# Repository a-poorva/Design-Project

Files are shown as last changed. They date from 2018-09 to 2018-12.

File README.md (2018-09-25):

# Design-Project

Design Skills Project (Variable Light Intensity)

Functional Specifications

1. LED light that is button-activated to switch between the following operating modes:
a. Off
b. Brightest
c. Intermediate Brightness
d. Least Bright
e. Flashing @ 2 Hz
2. Self-contained device with LED and button exposed.

Extra credit possibilities:
1. Battery life indicator
2. Waterproof enclosure
3. You tell us!

Constraints
1. Run on single battery up to 9 V
2. Electronics connected to a single PCB (can be single- or double-sided)
3. Cannot weight more than 1 lb
4. Cannot have a single dimension > 6 in
5. Cannot cost more than $50 to duplicate unit
6. Battery must be easily replaceable

Evaluation
1. Minimize weight
2. Minimize size
3. Maximize Brightest mode
4. Minimize power draw / maximize battery life
5. Survive 3 foot drop with battery installed

Create-and-maintain a GitHub project repository to maintain version history of:
1. Mechanical CAD (PDFs + more)
2. Electronic CAD (PDFs + more)
3. Software
4. Testing data
5. Design history / notes
6. Specification sheets
7. Usage notes (README.md)
8. Kanban board / Issues / Milestones

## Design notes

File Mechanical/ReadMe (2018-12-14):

Mechanical Design

There are two designs, one being the elliptical cylinder design with magnets and the other being the black box for the Arduino Uno.

The cylinder has:
--> USB port
--> holes for LED/switch
--> Magnets

The box has 
--> holes for LED/Switch
--> Grooves on the lid
--> threaded holes for adding screws

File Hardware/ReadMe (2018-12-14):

Components used include:

1. Arduino Uno --> The PCB here is not routed as I used a protoboard. I have laid out the components as it might look on the shield.
2. Pushbutton - Adafruit
3. Resistors - R1, R2 -0402-01/16W-1%, SparkFun (100k)
4. Battery - G1, AB9V
5. LED - LED2, 5MM, Adafruit
6. Arduino Nano --> The PCB here is routed as I etched this board.

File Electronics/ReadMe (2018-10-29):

Electrical Schematics should allow for 

1. Variable intensity of light
2. On/Off 
3. Blinking at 2Hz

Components used: Arduino (nano?), LED, bypass capacitor, switch, voltage regulator

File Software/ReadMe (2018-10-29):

Making use of Arduino (nano?)

Things to focus on:
1. Interrupts
2. Switching between cases and making sure that the interrupt functions for each case

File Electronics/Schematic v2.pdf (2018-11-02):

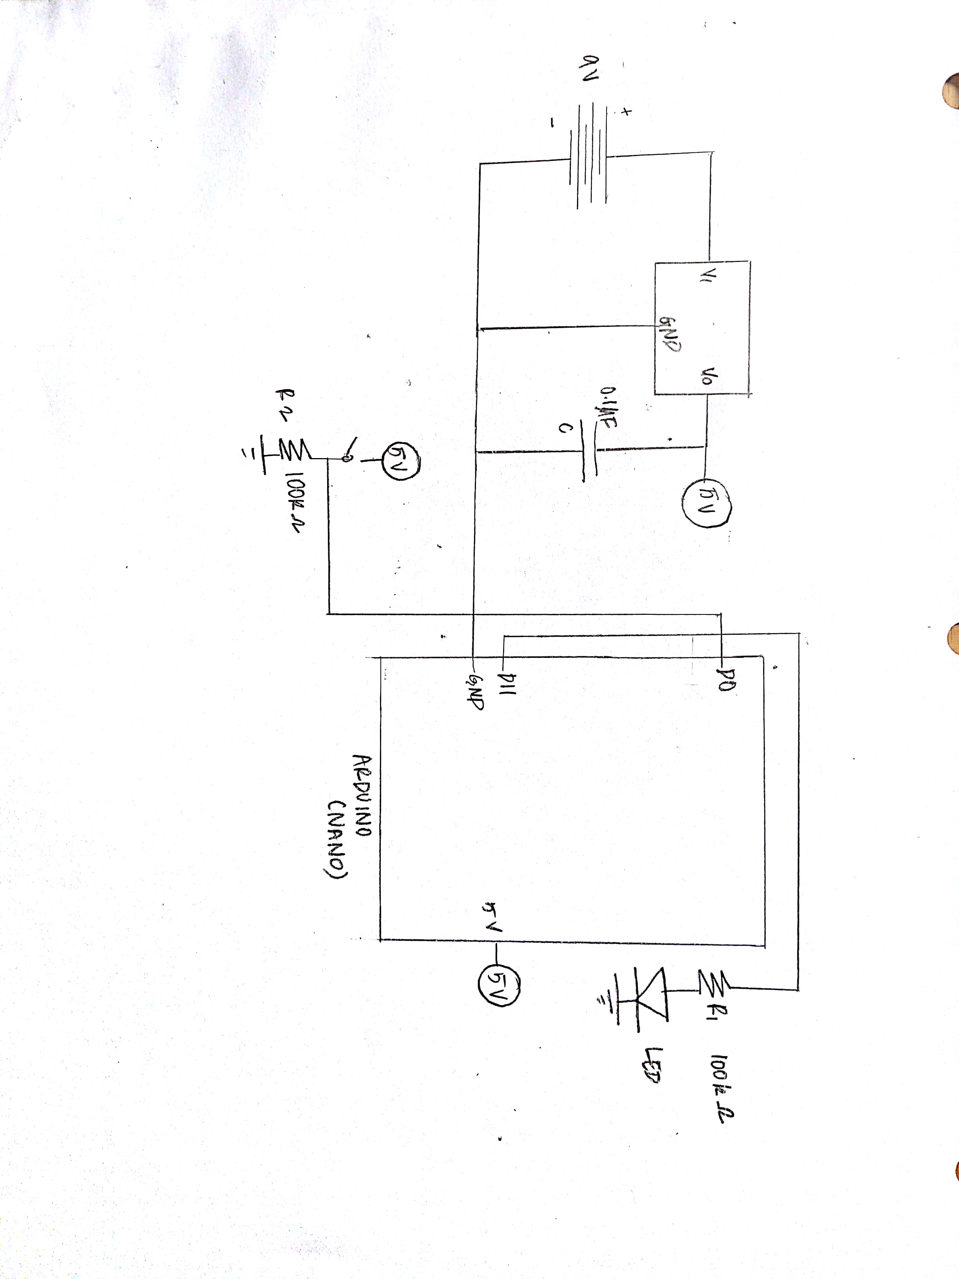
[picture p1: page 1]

Scanned by CamScanner

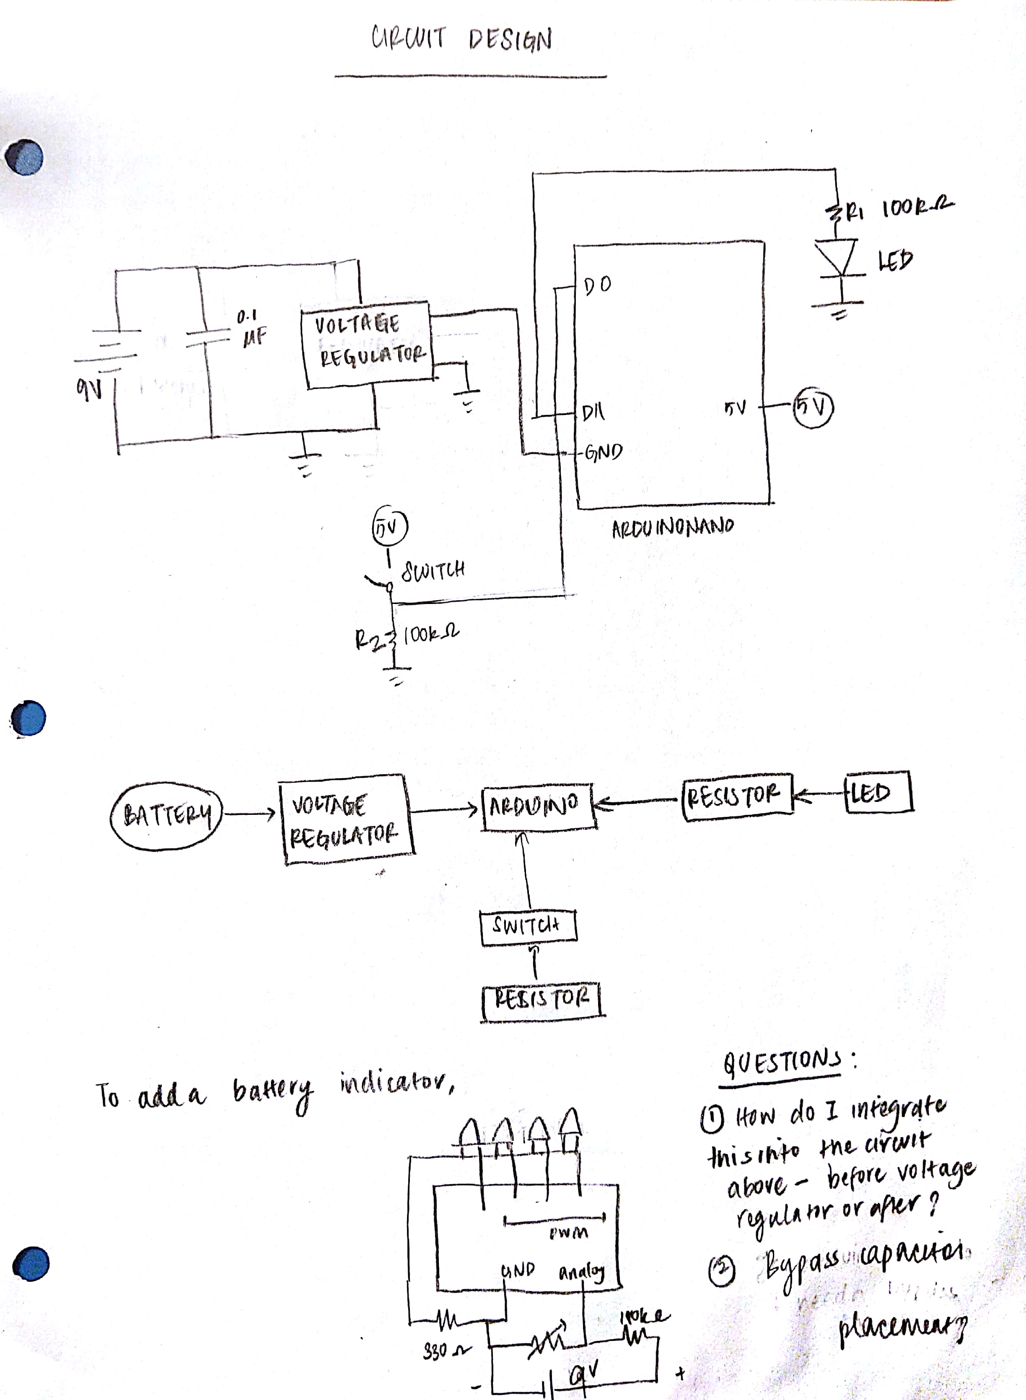
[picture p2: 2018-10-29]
Electronics/Electrical Schematic.jpg

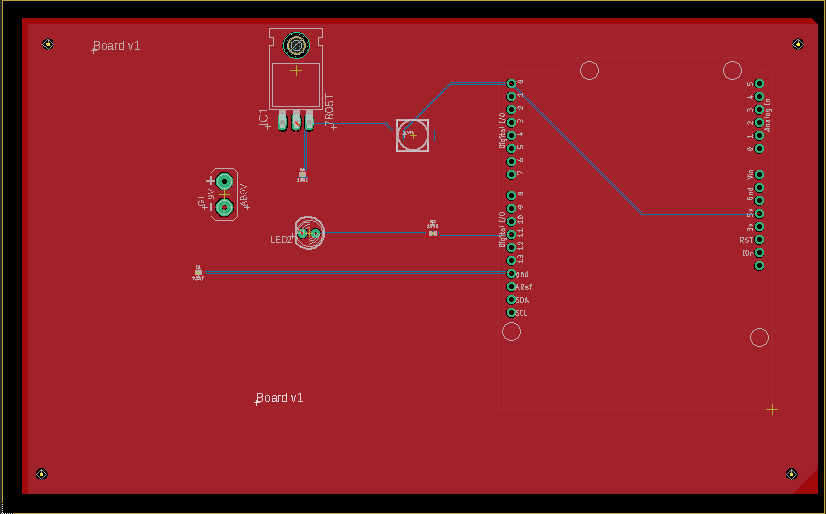
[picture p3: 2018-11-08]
Hardware/PCB in progress.png

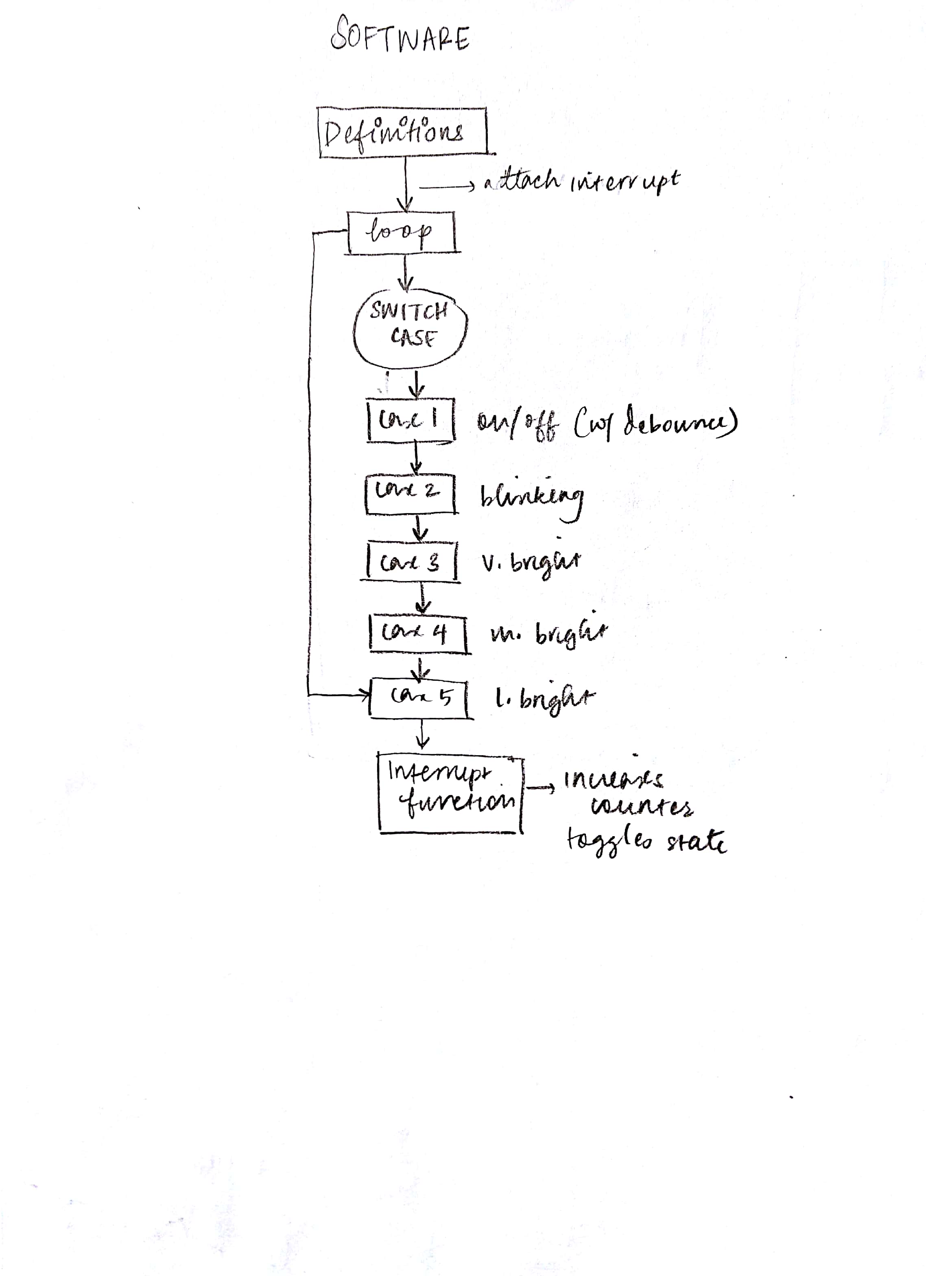
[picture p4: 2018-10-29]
Software/Flowchart.jpg

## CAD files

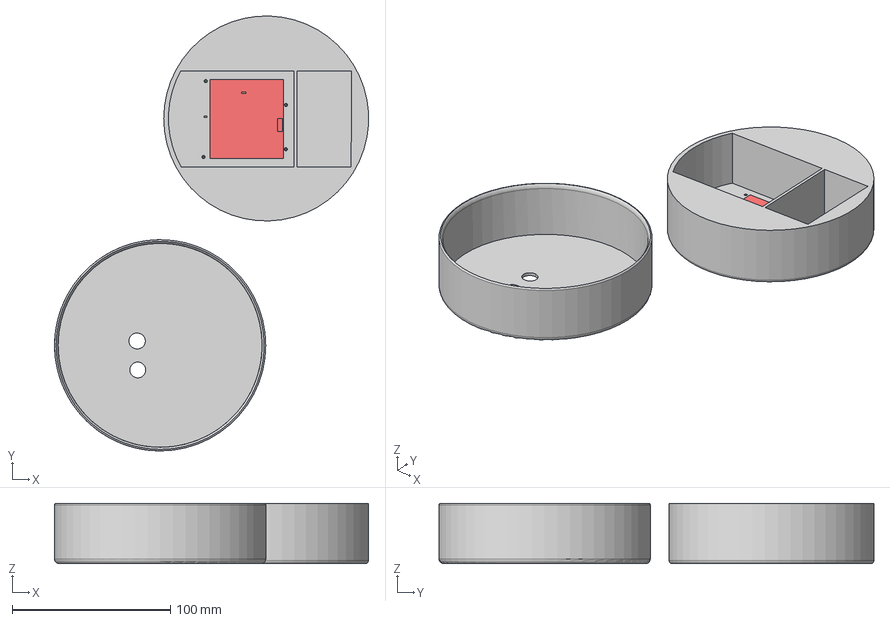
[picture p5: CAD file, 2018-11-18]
Mechanical/Cylinder3D v1.step
198.4 x 274.9 x 38.1 mm
Board
AB9V
LED5MM
100K
PUSHBUTTON_SMD_SJ
ARDUINOR3-BPLACE

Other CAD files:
Mechanical/Cylinder3D v1.f3d
Mechanical/Magnets_Design v1.f3d
Mechanical/Magnets_lid.f3d
Mechanical/arduino_body v1.f3d
Mechanical/arduino_lid v1.f3d
Mechanical/magnetidea v1.f3d
Mechanical/slidingdoor v1.f3d

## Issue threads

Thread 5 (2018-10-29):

Integration of Battery Indicator and placement of Bypass Capacitor

a-poorva, 2018-10-29:
- Not entirely sure how to integrate the battery indicator - while I have a rough circuit for it (the different LED's shown indicate different battery ranges), would I add this before the voltage regulator and bypass capacitor, or..?
- LIttle confused about the placement of the bypass capacitor, and if one is required after the voltage regulator as well since I plan on using an Arduino Nano.

a-poorva, 2018-11-04:
After a little research, I added a bypass capacitor to my circuit (check out Schematic v2). Would

Closed 2018-11-09.

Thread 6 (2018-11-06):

Software Review

a-poorva, 2018-11-06:
I'm having some problems with

1. Bouncing
I'm not sure what my program isn't accounting for.

2. Brightness changes
The LED isn't really getting any brighter, or less? Not sure what to change in my program. Should I just assign specific values for each level of brightness and remove the if statement?

mlp6, 2018-11-06:
It looks like you are using `digitalRead()` instead of `analogWrite()` for the PWM output in some of your case statements; am I misreading that?

W/r to the bouncing, what happens if you modulate the debounce delay?

mlp6, 2018-11-24:
I am not sure I totally follow how your debouncing logic should be working, but one thing I would be careful with with this line:
https://github.com/a-poorva/Design-Project/blob/8bf33d13c4cfb9eff1144b0b43db92085eee905f/Software/LEDv3.ino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

`ledState` is declared as an `int`; you are using it in that line more like a `bool`; can you declare it as a `bool` instead so that you can just toggle the state?  Also, I'm not a huge fan of assigning the value by flipping logical state; it would be easier to follow if you explicitly set and tested "on" and "off" states for the button.

a-poorva, 2018-12-02:
Hi Dr. Palmeri,

So I fixed my code a little, and while it changes states smoothly, the whole thing just runs on a loop continuously, not sure why. Would you mind taking a look at my code?

mlp6, 2018-12-03:
Your `loop()` function doesn't seem to ever call `button_press()`.

Closed 2018-12-05.

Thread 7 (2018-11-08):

PCB design

a-poorva, 2018-11-08:
1. I still have to assign this to Matt Brown, Dr. Richardson and Brinnae, since I sent them collaborator requests only last night/this morning. I'll add them later.
2. I started on my PCB design by adding polygon pores and then routing, but some of my connections seemed to disappear when I did that. Brinnae suggested routing and then adding polygon pores, and ripping up the ground connections? I'm a little confused about that, as well as to how to proceed beyond that (in terms of adding holes, vias, etc.)
3. Can I cut out all that extra space when I create my polygons?

a-poorva, 2018-11-09:
When I showed my design to Matt Brown today, he mentioned that part of the reason why my battery is just sort of floating around is because I didn't connect the Vcc in my schematic, though I labelled it?? Besides drawing connections between them, is there a more elegant way of approaching this problem?

a-poorva, 2018-11-09:
So I tried adding the source with the net tool, and I tried to reroute it but I noticed a problem(?) I saw last time as well:

1. My switch only has one connection?
2. The positive terminal of my battery doesn't seem to be connected to anything, but both connections seem to arise from the ground terminal.

Not sure what the issue is.

mlp6, 2018-11-09:
Will take a look in the morning.

a-poorva, 2018-11-09:
Uploaded a new version! Does this look a little better?

sphaerobolus, 2018-11-12:
Rather than creating new files for each version, take advantage of the version control system: Just upload the new version. The old version is still available as an old version of the same file.

Bypass capacitor C1 would be better between the regulator output and ground. It's not doing much good as used here, and might be doing harm.

Change the 100k current limiting resistor to a real value.

If you're doing this as a shield, do you even need the regulator? You could use Arduino's the on-board regulator. You pass through the Arduino's regulator if you use Vin stead of 5V as your supply.

a-poorva, 2018-11-13:
Thanks for your help, Matt! I've uploaded a new one (I have been uploading all my files so far, using the 'Upload files' button! Is that not the right way to do this?). Hope this one is better.

sphaerobolus, 2018-11-14:
I didn't use the right terminology when I suggested not creating new files. if you're using the desktop git client, the things you want to be doing are "commit" to save a new version of an existing file and "push" to put the file on the github server. If you're using the web client, I'm not sure what the best process is. You could edit the file, then paste in the new version and save it. You definitely don't want a bunch of files named "abcdv1.brd" and "abcdv2.brd". The git ecosystem takes care of the versions, you just commit new versions of existing files.

The board is looking good! Now I think all you need is to increase the width of traces. You can probably get away with 20mil, so go for that.

a-poorva, 2018-11-16:
Right. I'll be sure to look up how exactly to do that.

Thanks for your help!

Closed 2018-11-16.

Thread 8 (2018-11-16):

Header pins

a-poorva, 2018-11-16:
I just realised that I used the arduino board in my PCB instead of header pins. Is this the right way to do this? I'm not sure I understand the difference here.

sphaerobolus, 2018-11-17:
If you want this to be a shield for your Uno, you need to line up your connections to the Uno. To do this, you placed the Uno board as a component. If I understand you correctly, you might just be confused over semantics. Are you placing the Uno on your board? Or your board on the Uno? Doesn't matter, the holes still line up.

After fabricating the board, you'll put header pins in all those holes around the perimeter, then plug your board into the Uno.

Did I answer the right question?

a-poorva, 2018-11-17:
Right, so it doesn't matter, essentially, whether you use header pins or the actual board in your design, as long as the pins line up?

mlp6, 2018-11-17:
Yep!

Closed 2018-11-17.

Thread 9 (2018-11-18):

Cylinder Idea

a-poorva, 2018-11-18:
Please see the uploaded designs for reference.

I'm having a few problems with the following:

1. The arduino seems to be underneath the whole cylinder? I'm not sure why that's happening, or if I"m misinterpreting the design.
2. I wanted to have the lid of the cylinder screw on. I'm not sure if I've done the threading correctly.
3. The holes I've made in the lid seem to vanish whenever I try to dimension them - is this because I've made them incorrectly, or is there some other reason?
4. I'm a little uncertain about the dimensions of the holes I've made. Is there a stanard size we're supposed to use?

Any other feedback would be great!

ps178, 2018-11-19:
Could you upload the .f3d version of your CAD design.
You also need to upload the 2D rendering of your design. You can find this under MODEL -> drawing

a-poorva, 2018-11-19:
Done and done!

ps178, 2018-11-20:
1) Yes, your PCB is underneath the cylinder. This is because you sketched the cylinder on the same plane as where you placed the board. Usually, you would create you casing based on the PCB & arduino dimensions and then you can assemble with the 3d PCB rendering to make sure everything fits together. Does that make sense? I think you can create you circle first and then insert your PCB.

2) I think the threads look good. You have them going in different directions so they should fir together given their thread size and count are the same.

3) It looks like you made two holes with 10 mm diameter. Is that not what you were trying to do? Also, instead of using the 'holes' command you can also sketch a circle and the extrude in the opposite direction to carve out the circle onto another surface.

4) The holes for the LED & button or the holes for mounting the arduino?

sphaerobolus, 2018-11-23:
I'm not sure you'll be able to print a thread suitable for a project like this. Our FDM printers are pretty low resolution. (An SLA printer has hope of printing some threads.)

You have two options: You can print a hole suitable for a wood screw or self-tapping screw. This screw would form its own threads in the plastic the first time you put it in.

Better, I think, are heat-set thread inserts. You form a hole with a little bit of taper (a/k/a draft angle). The top of the hole is just big enough for the end of the insert to fit in "dry". After dry-fitting, you use a heat source, such as a soldering iron, to melt the insert into the plastic. You can google the process. The inserts I have are from this page:

https://www.mcmaster.com/catalog/124/3395

We have the tapered inserts in 2-56, 3-56, 4-40, and 6-32.

Closed 2018-12-05.

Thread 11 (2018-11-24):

Magnet Idea

a-poorva, 2018-11-24:
After considering Matt's feedback (the cylinder thing is still on the table, I'm looking into the information he sent me {thanks Matt!}), I had an alternate idea which you can find in the Mechanical Design folder.

Here, I wanted to have the lid snap on to the box with a magnet - i.e, I would have a magnetic strip along the edge of the lid and the box (around 1 mm width).

Would that be possible?

sphaerobolus, 2018-11-25:
Certainly possible. I have many magnets sitting around, but they're all significantly larger than that. See if you can find something at kjmagnetics.com

a-poorva, 2018-11-26:
Will do, thank you!

Closed 2018-12-05.

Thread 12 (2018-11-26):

Sliding Door Idea

a-poorva, 2018-11-26:
Would this be possible to print such that the piece that slides in moves smoothly?

mlp6, 2018-11-26:
Can this be printed... yes, especially if the overhanging notch isn't too much to require supports to be printed that could be really tricky to get out and remain smooth... but "smooth" operation will really be dependent on the quality of the print and making sure that you allow for some tolerance in that sliding piece.

@sphaerobolus can comment on the specifics of the printers that he runs to see what he would recommend.  We've done sliding access in the past; most have worked.

ericsrichardson, 2018-11-26:
One thought on sliding doors - it's often helpful to round off the two corners on the leading edge of the sliding door (if I'm understanding what you want to do correctly) so that when you slide the door into the slots, the corners don't bind inside the slots.

sphaerobolus, 2018-11-26:
Also, watch for clearances. The printers overprint, meaning the parts can end up being slightly larger than you designed. If I have two parts that I need to nest, I usually make a difference of at least 0.020". Say my nominal dimension is 0.5". I might make one part 0.49" (or maybe smaller) and the other 0.51" (or maybe larger).

Closed 2018-12-05.

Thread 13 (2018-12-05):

Circuit

a-poorva, 2018-12-05:
Hello,

My PCB hasn't been working the last few times, so I just wanted to be sure that this circuit makes sense before I etched another board. @sphaerobolus @mlp6 would you mind taking a look?

a-poorva, 2018-12-05:
Neither the LED nor the button were working in the previous boards.

mlp6, 2018-12-05:
okey dokey - I'll take a peek this evening

Closed 2018-12-14.

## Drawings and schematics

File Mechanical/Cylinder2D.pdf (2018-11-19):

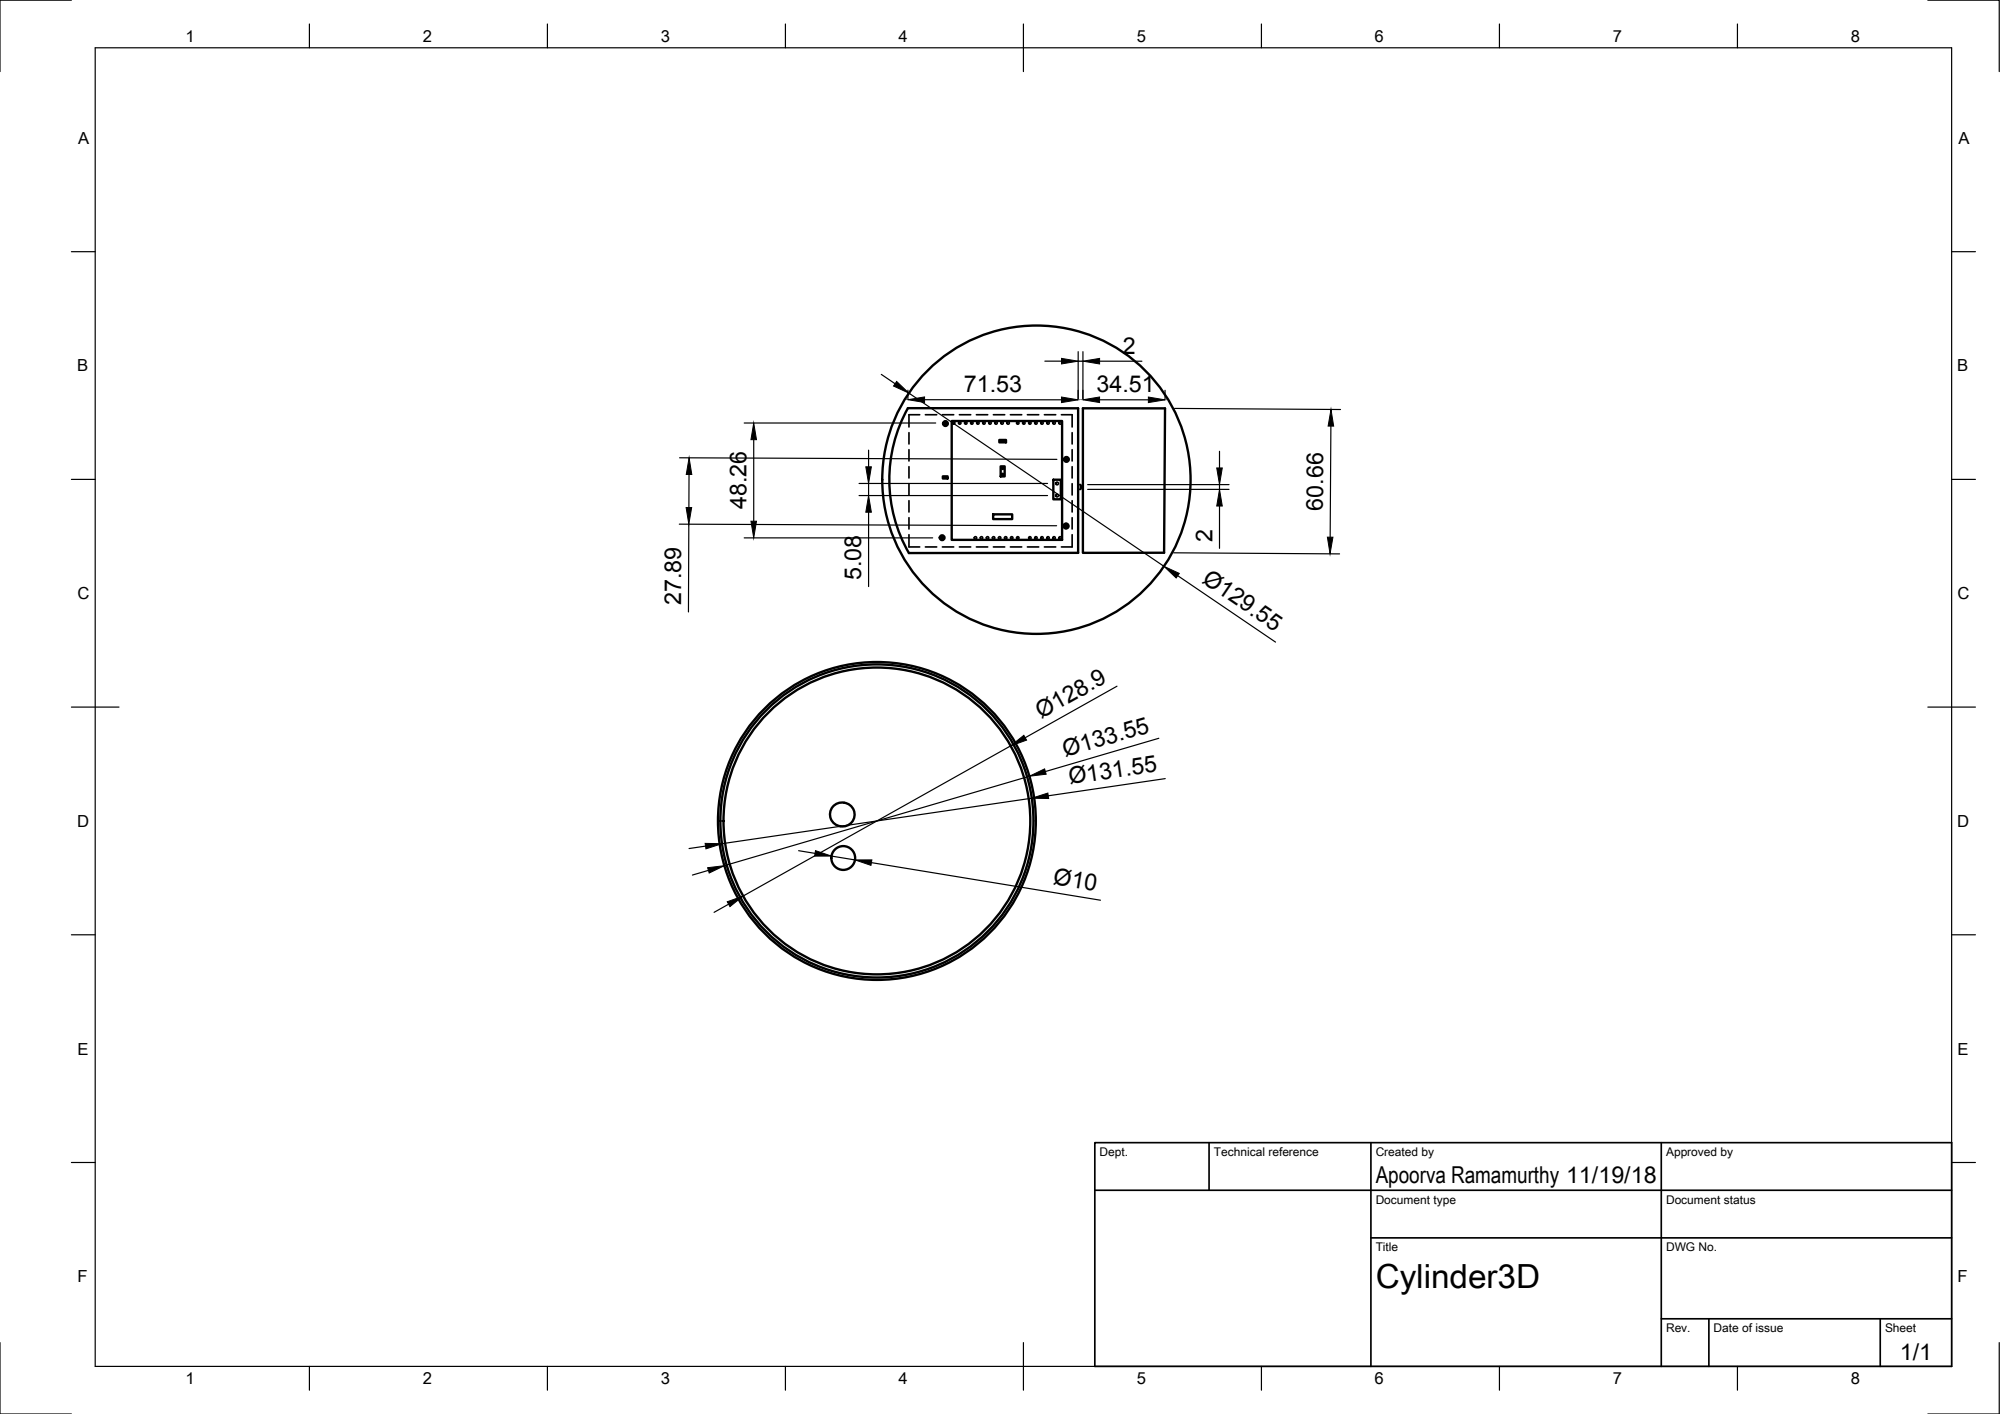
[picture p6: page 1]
Apoorva Ramamurthy 60.66

Dept. | Technical reference | Created by 11/19/18 | Approved by

Document type | Document status

Title Cylinder3D | DWG No.

Rev. | Date of issue | Sheet 1/1

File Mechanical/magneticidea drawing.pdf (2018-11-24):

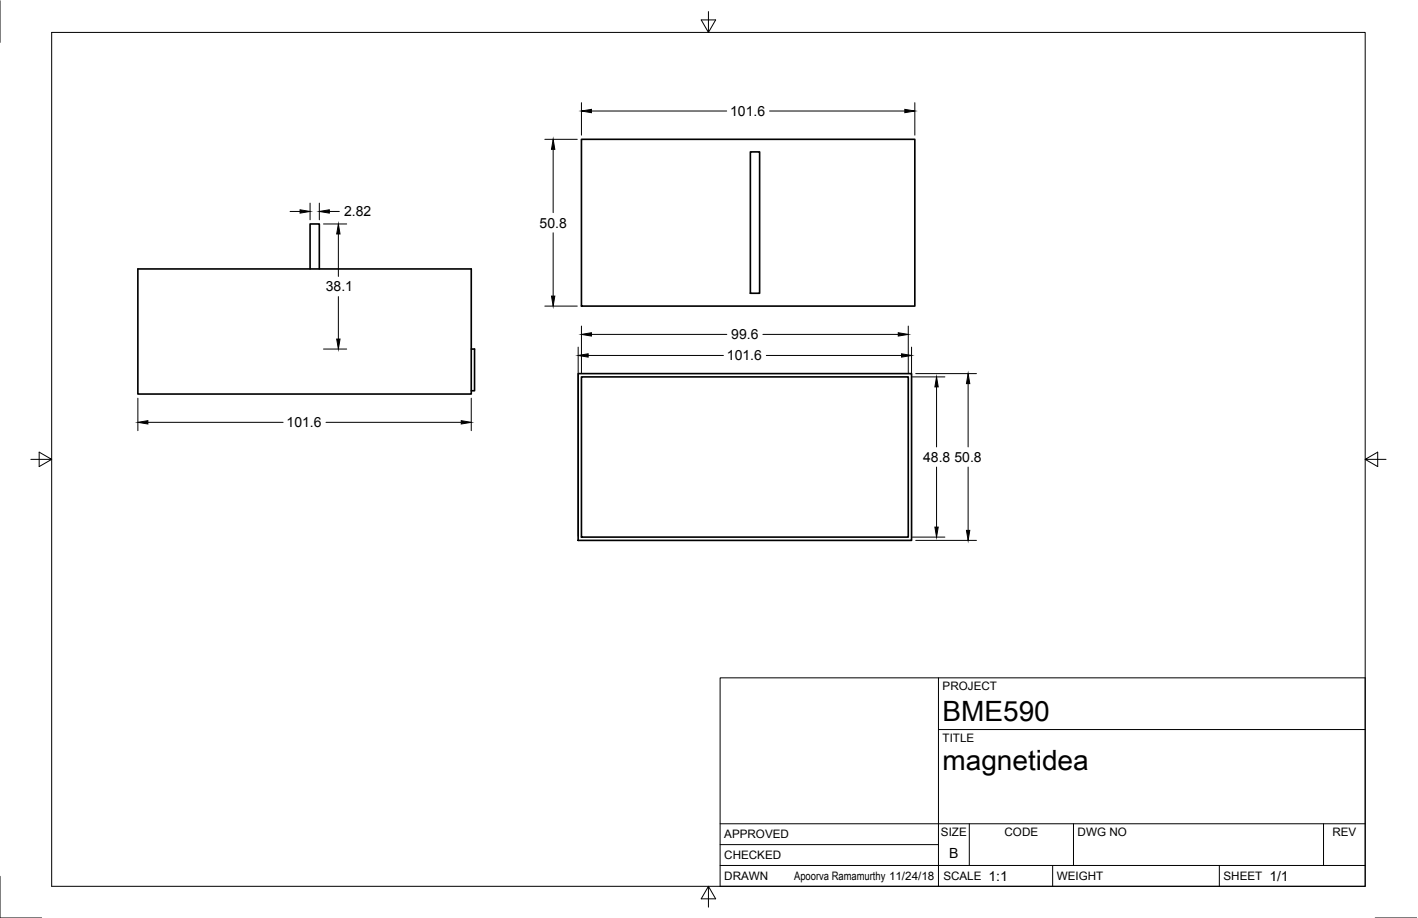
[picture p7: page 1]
SIZE; CODE; DWG NO; REV; Apoorva Ramamurthy 11/24/18

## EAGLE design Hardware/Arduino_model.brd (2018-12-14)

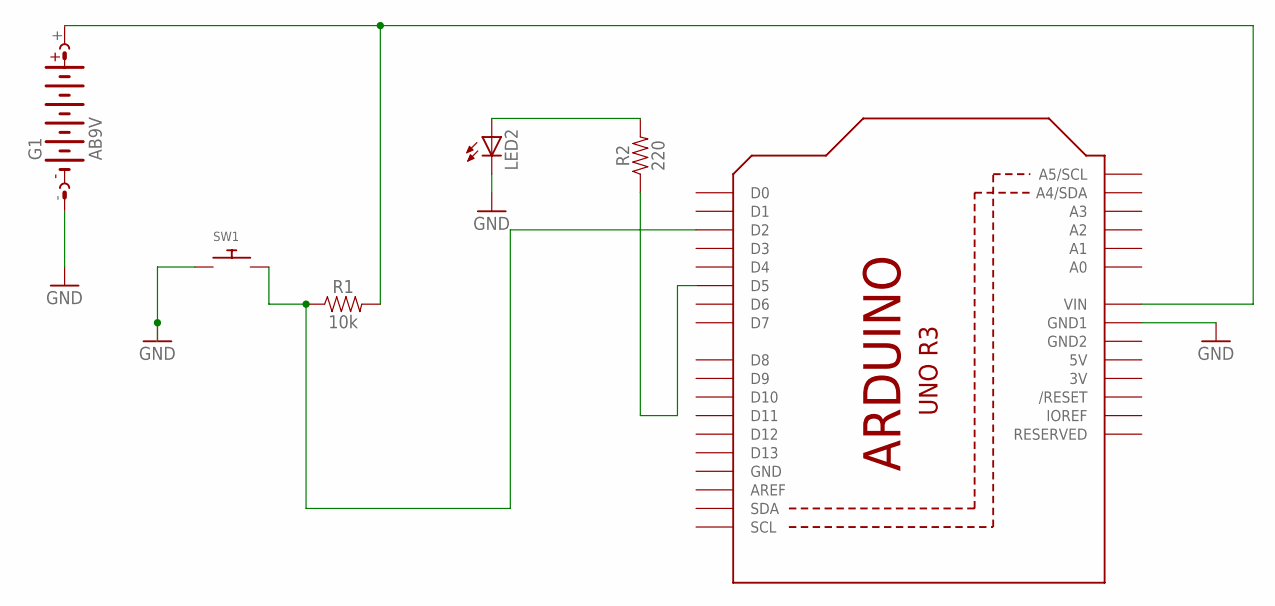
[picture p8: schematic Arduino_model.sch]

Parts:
G1: AB9V
LED2: LED5MM
R1: 10k; AXIAL-0.1
R2: 220; 0603
SW1: SWITCH_PUSHBUTTONEVQ-PE; TACT_PANA-EVQ
U1: ARDUINOR3-DIMENSION; ARDUINOR3

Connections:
3V: U1.3V
5V: U1.5V
GND: G1.-, LED2.K (C), SW1.P$1, U1.GND, U1.GND1
GND2: U1.GND2
unnamed: G1.+, R1.P$2 (2), U1.VIN
unnamed: R1.P$1 (1), SW1.P$2, U1.D2
unnamed: R2.1, U1.D5
unnamed: LED2.A, R2.2

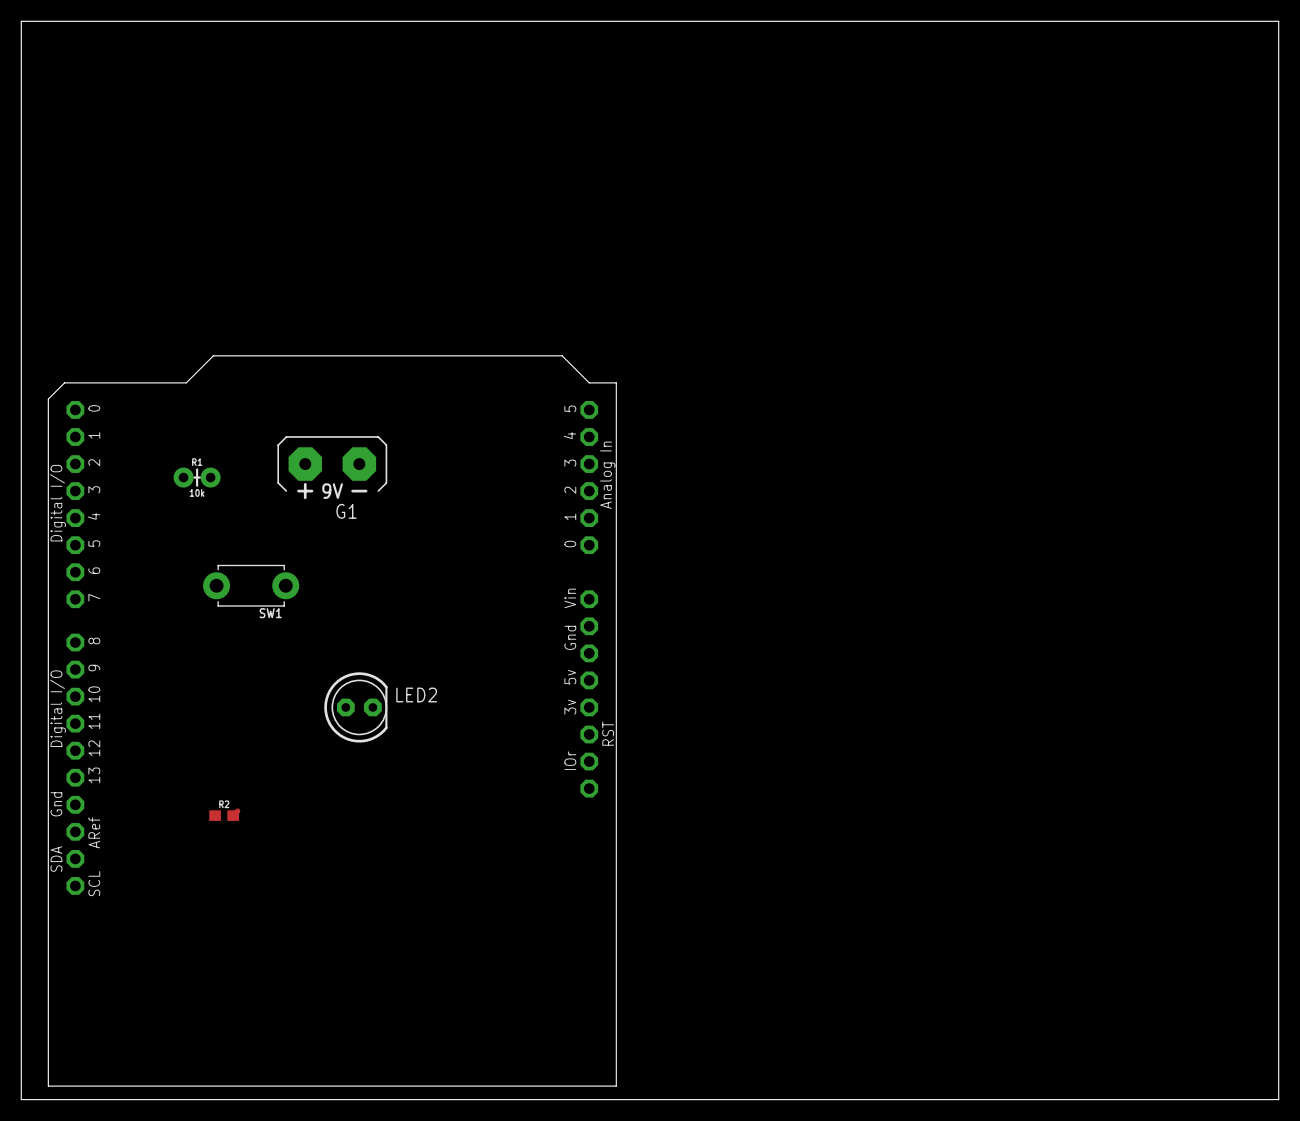
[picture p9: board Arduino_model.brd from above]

Board: 2 copper layers, 118.1 x 101.3 mm, 6 parts (0 on the bottom side), 5 nets.

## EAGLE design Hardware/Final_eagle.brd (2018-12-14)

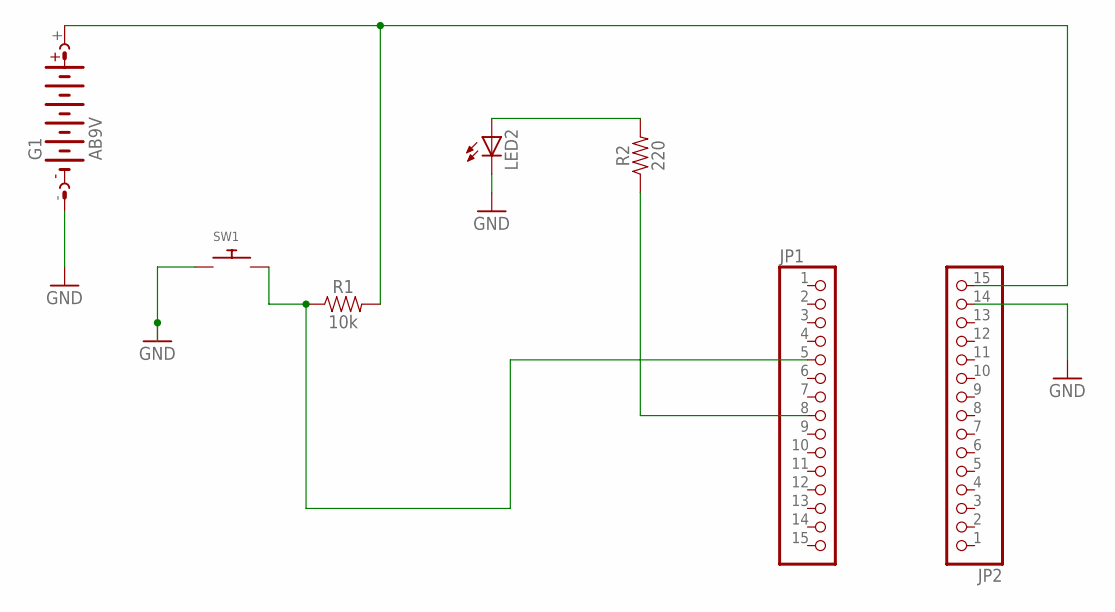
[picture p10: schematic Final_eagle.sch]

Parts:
G1: AB9V
JP1, JP2: PINHD-1X15; 1X15
LED2: LED5MM
R1: 10k; AXIAL-0.1
R2: 220; 0603
SW1: SWITCH_PUSHBUTTONEVQ-PE; TACT_PANA-EVQ

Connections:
GND: G1.-, JP2.14, LED2.K (C), SW1.P$1
unnamed: G1.+, JP2.15, R1.P$2 (2)
unnamed: JP1.5, R1.P$1 (1), SW1.P$2
unnamed: JP1.8, R2.1
unnamed: LED2.A, R2.2

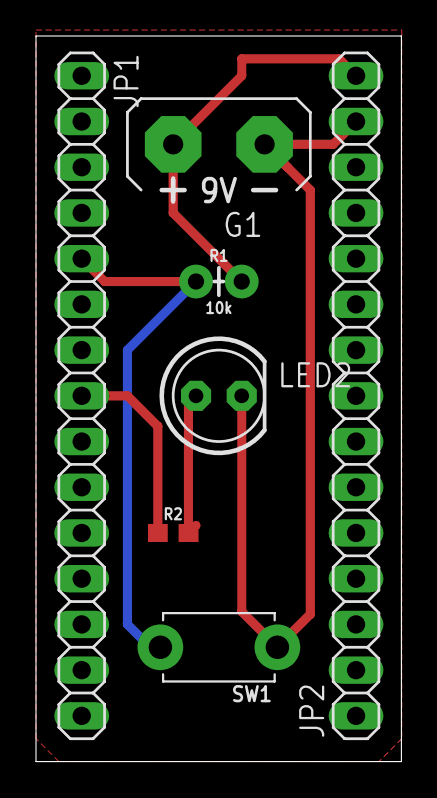
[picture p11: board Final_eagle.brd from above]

Board: 2 copper layers, 20.3 x 40.3 mm, 7 parts (0 on the bottom side), 5 nets.

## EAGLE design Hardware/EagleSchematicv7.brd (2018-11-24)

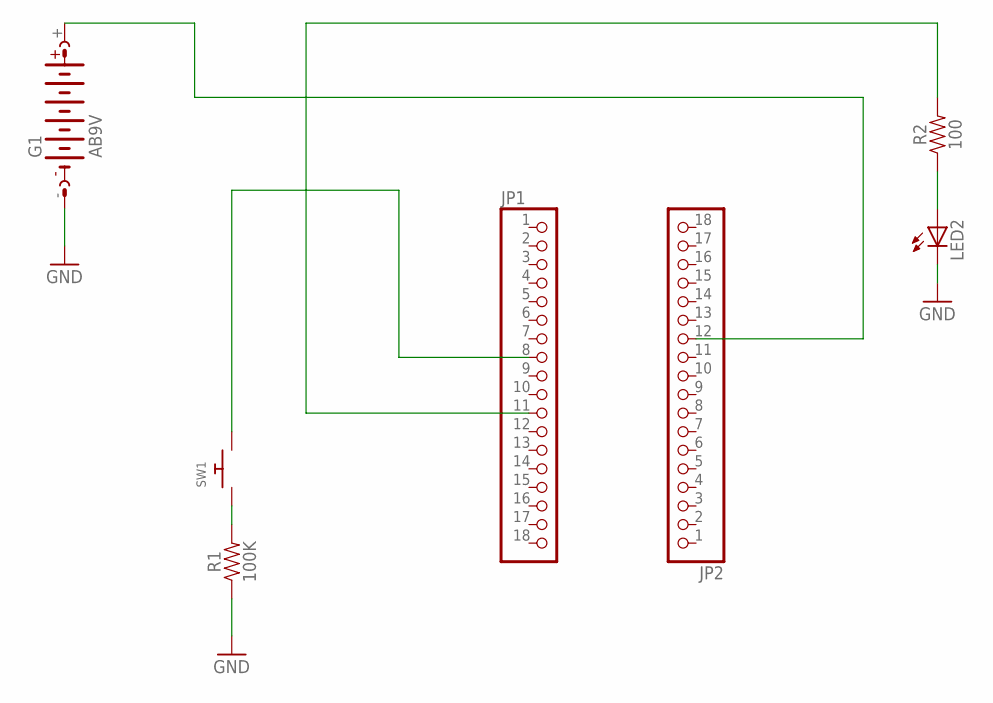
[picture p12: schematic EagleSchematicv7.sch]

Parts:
G1: AB9V
JP1, JP2: PINHD-1X18; 1X18
LED2: LED5MM
R1: 100K; 0402
R2: 100; 0603
SW1: SWITCH_PUSHBUTTONSOFTTOUCHSMD_SJ; PUSHBUTTON_SMD_SJ

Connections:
GND: G1.-, LED2.K (C), R1.1
unnamed: G1.+, JP2.12
unnamed: R1.2, SW1.P$1
unnamed: JP1.8, SW1.P$2
unnamed: JP1.11, R2.2
unnamed: LED2.A, R2.1
unnamed: JP1.10, JP2.2

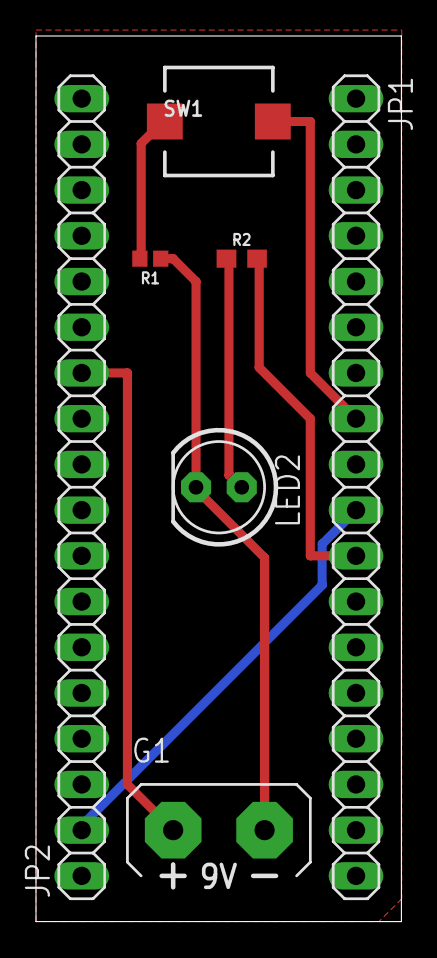
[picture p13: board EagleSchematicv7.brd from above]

Board: 2 copper layers, 20.3 x 49.2 mm, 7 parts (0 on the bottom side), 7 nets.

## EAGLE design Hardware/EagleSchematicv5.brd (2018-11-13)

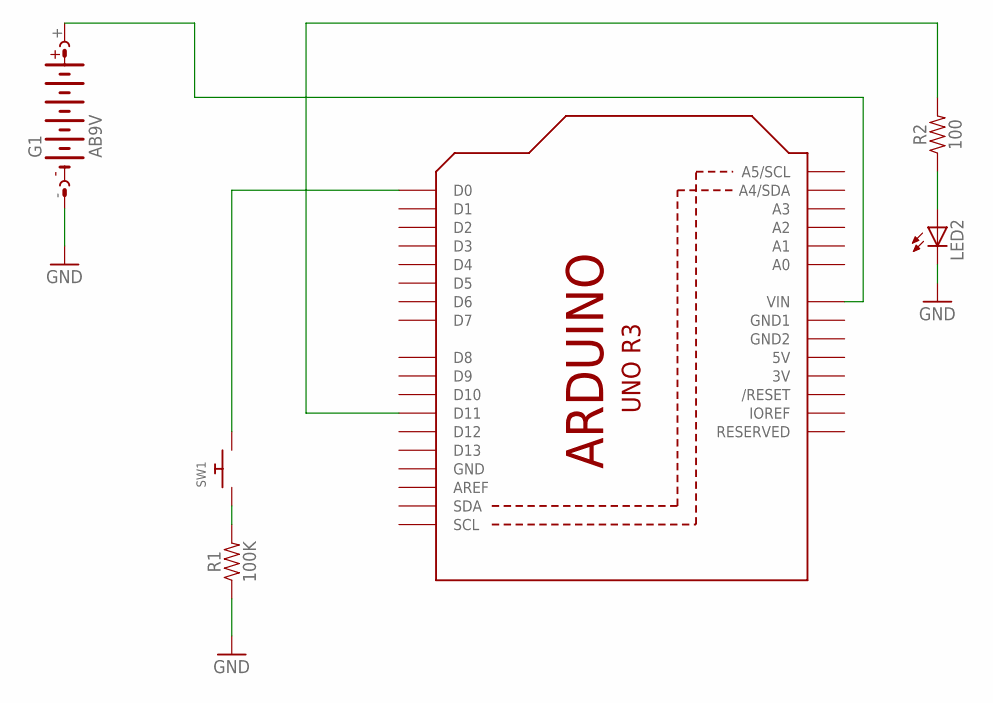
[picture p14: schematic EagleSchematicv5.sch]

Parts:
G1: AB9V
LED2: LED5MM
R1: 100K; 0402
R2: 100; 0603
SW1: SWITCH_PUSHBUTTONSOFTTOUCHSMD_SJ; PUSHBUTTON_SMD_SJ
U1: ARDUINOR3-BPLACE

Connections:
3V: U1.3V
5V: U1.5V
GND: G1.-, LED2.K (C), R1.1, U1.GND
GND1: U1.GND1
GND2: U1.GND2
unnamed: G1.+, U1.VIN
unnamed: R1.2, SW1.P$1
unnamed: SW1.P$2, U1.D0
unnamed: R2.2, U1.D11
unnamed: LED2.A, R2.1

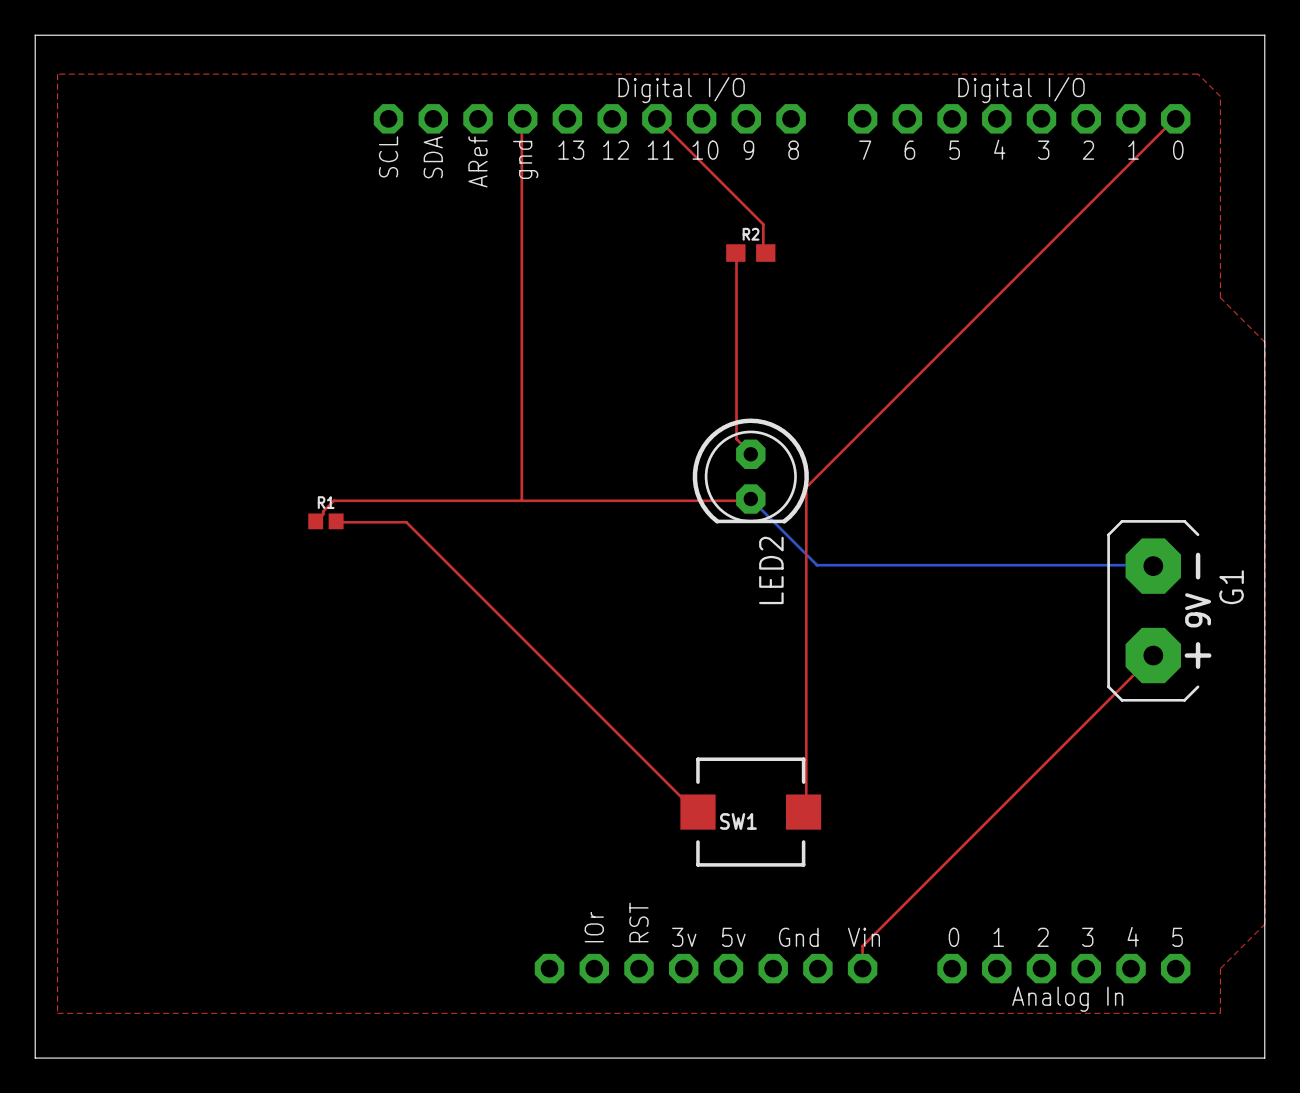
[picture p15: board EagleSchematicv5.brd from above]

Board: 2 copper layers, 69.8 x 58.1 mm, 6 parts (0 on the bottom side), 6 nets.

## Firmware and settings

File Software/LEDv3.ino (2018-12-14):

//defining pins - preprocessor directives 
#define flashingRate 2
#define buttonPin 2
#define ledPin 5

//defining variables 
int counter = 0;
unsigned long previousMillis = 0;
unsigned long currentMillis = 0;
unsigned long lastButtonTime = 0; 
unsigned long debounceTime = 200;
int baudValue = 9600;
int low = 70;
int medium = 160;
int high = 255;
int frequency = 1000 / flashingRate;

//introducing starting state of button and LED
int ledState = LOW;
bool buttonState = false;


void setup() {
  pinMode(buttonPin, INPUT);
  
  pinMode(ledPin, OUTPUT);

  //interrupt
  attachInterrupt(digitalPinToInterrupt(buttonPin), button_press, FALLING);

  //serial
  Serial.begin(baudValue);
}

void loop() {
  debounce_func();
  LED_states();
  Serial.print("Your bike light is in state: "); //you can use this to debug states
  Serial.println(counter);
}

//debouncing function
void debounce_func(){
  if ((millis() - lastButtonTime) > debounceTime){
    buttonState = true;
    lastButtonTime = millis();
  }
}


//interrupt
void button_press() {
  if (buttonState) {
    counter += 1;
    buttonState = false;
  } 
  if (counter > 4) { //to make sure the counter doesn't go on forever --> easier to debug this way
    counter = 0;
  }
}

void flashing_func() { //to flash the LED at a certain frequency 
  currentMillis = millis();
      if (currentMillis - previousMillis >= frequency) {
        previousMillis = currentMillis;
        if (ledState == LOW) {
          ledState = HIGH;
        }
        else {
          ledState = LOW;
        }
      }
      digitalWrite(ledPin, ledState);
}

//switching states
void LED_states() {
  switch (counter) {
    case 0: //off
      analogWrite(ledPin, 0);
      break;
    case 1: //low brightness
      analogWrite(ledPin, low);
      break;
    case 2: //medium brightness
      analogWrite(ledPin, medium);
      break;
    case 3: //high brightness
      analogWrite(ledPin, high);
      break;
    case 4:
      //flashing using millis
      flashing_func();
      break;
     
      
      
   }
}

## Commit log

2018-11-02 Electronic Schematic v2
2018-11-08 Add files via upload
    Schematics v1 using Eagle
    [Schematic3.sch]
2018-11-08 Schematic v1
    Hopefully with the right parts!
2018-11-08 Eagle Schematic v1
    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
    [EagleSchematic.sch]
2018-11-08 still working on it
    [EagleSchematic.brd]
2018-11-08 PCB design and layout
2018-11-08 in progress
    [EagleSchematic.brd, EagleSchematic.sch]
2018-11-08 ready for review
    [EagleSchematic.sch]
2018-11-09 v2 - needs attention
    [EagleSchematicv2.brd, EagleSchematicv2.sch]
2018-11-09 v3 - review
    [EagleSchematicv3.brd, EagleSchematicv3.sch]
2018-11-13 to be reviewed
    [EagleSchematicv4.brd, EagleSchematicv4.sch]
2018-11-18 see readme
    [Cylinder2D v1.step, Cylinder3D v1.step]
2018-12-14 Please refer to readMe
    [Arduino_model.brd, Arduino_model.sch]
2018-12-14 New box
    [arduino_body v1.f3d, arduino_lid v1.f3d]

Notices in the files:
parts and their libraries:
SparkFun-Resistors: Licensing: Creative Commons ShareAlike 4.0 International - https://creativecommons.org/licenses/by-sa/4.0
